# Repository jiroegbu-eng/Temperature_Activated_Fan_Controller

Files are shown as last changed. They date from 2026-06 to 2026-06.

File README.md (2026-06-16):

# Temperature-Activated Fan Controller

A 12V fan controller circuit designed in KiCad. The board turns a cooling fan on or off based on temperature using a 10k NTC thermistor, an LM358 comparator, and an IRLIZ44N MOSFET.

This project is part of my electronics design portfolio. The focus was on building a practical thermal management circuit with a clean schematic, routed PCB layout, and proper ERC/DRC verification.

## Project Summary

The circuit senses temperature through an NTC thermistor voltage divider. A 10k potentiometer sets the fan turn-on threshold. The LM358 compares the thermistor voltage against the threshold voltage, then drives the MOSFET gate when the fan should turn on.

The fan is switched using a low-side MOSFET arrangement. The fan positive terminal is tied to +12V, while the MOSFET controls the ground side of the fan. A 1N4007 diode is placed across the fan output to protect the MOSFET from voltage spikes when the fan turns off.

## Why I Built This

This project is more practical than a simple light sensor circuit because thermal control is common in real electronics systems. Power supplies, motor drivers, amplifiers, embedded boards, and battery systems often need basic fan control or thermal protection.

The project demonstrates:

* Analog sensor interfacing
* Comparator-based switching
* Adjustable threshold control
* Hysteresis feedback
* MOSFET load switching
* Inductive load protection
* PCB layout for power and signal separation

## Main Specifications

| Item | Detail |
| --- | --- |
| Supply voltage | 12V DC |
| Temperature sensor | 10k NTC thermistor @ 25°C |
| Comparator | LM358 |
| Switching device | IRLIZ44N N-channel MOSFET |
| Fan control method | Low-side switching |
| PCB type | 2-layer PCB |
| Design software | KiCad 10.0.1 |
| Simulation | Not included for this project |

## Circuit Operation

The NTC thermistor and a 10k resistor form a voltage divider. As temperature changes, the resistance of the thermistor changes, which also changes the voltage at the `TEMP_SENSE` node.

The 10k potentiometer creates an adjustable reference voltage called `REF_SET`. This lets the fan turn-on point be tuned manually.

The LM358 compares `TEMP_SENSE` against `REF_SET`. When the sensed temperature crosses the set threshold, the LM358 output changes state and drives the MOSFET gate through a 100Ω gate resistor.

The MOSFET switches the fan on the low side. This means the fan receives +12V directly, while the MOSFET connects or disconnects the fan’s ground path.

A 100k resistor provides hysteresis feedback from the comparator output back to the sensing node. This helps stop the fan from rapidly switching on and off when the temperature is close to the threshold.

## Key Design Choices

### NTC Thermistor Divider

The 10k NTC thermistor was paired with a 10k resistor to create a simple temperature-dependent voltage divider. Using equal nominal values around room temperature gives a useful mid-range voltage for the comparator input.

### Adjustable Threshold

A 10k potentiometer was used so the fan turn-on point can be adjusted without changing resistor values. This makes the circuit more flexible and easier to tune.

### Hysteresis Resistor

A 100k feedback resistor was added between the LM358 output and the temperature sensing node. This creates a small amount of hysteresis, which prevents fan chatter around the switching point.

### MOSFET Switching

The IRLIZ44N was selected because it is suitable for low-side switching of 12V fan loads and can be driven from a logic-level control signal. The MOSFET handles the fan current while the LM358 only drives the gate.

### Flyback Protection

The 1N4007 diode is placed across the fan output. Since a fan is an inductive load, it can produce a voltage spike when switched off. The diode gives that energy a safe path and protects the MOSFET.

### PCB Layout

The high-current fan path was routed with wider traces. The low-current sensor and comparator traces were routed separately using smaller traces. The thermistor was placed away from the MOSFET and fan output area to reduce unwanted heating and noise coupling.

## Main Components

| Reference | Component | Value / Part |
| --- | --- | --- |
| U1 | Op-amp / comparator | LM358 |
| Q1 | N-channel MOSFET | IRLIZ44N |
| RT1 | NTC thermistor | 10k @ 25°C |
| RV1 | Potentiometer | 10k |
| R1 | Divider resistor | 10k |
| R2 | Hysteresis resistor | 100k |
| R3 | Gate resistor | 100Ω |
| R4 | Gate pulldown resistor | 100k |
| R5 | LED current-limit resistor | 2.2k |
| D1 | Flyback diode | 1N4007 |
| D2 | Power indicator LED | LED |
| C1 | Decoupling capacitor | 100nF |
| C2 | Bulk capacitor | 10µF |
| J1 | Power input connector | 2-pin screw terminal |
| J2 | Fan output connector | 2-pin screw terminal |

## Verification

The design was checked in KiCad before finalizing the board.

| Check | Result |
| --- | --- |
| ERC | 0 errors |
| DRC | 0 errors |
| Unconnected items | 0 |

## Project Images

### Schematic

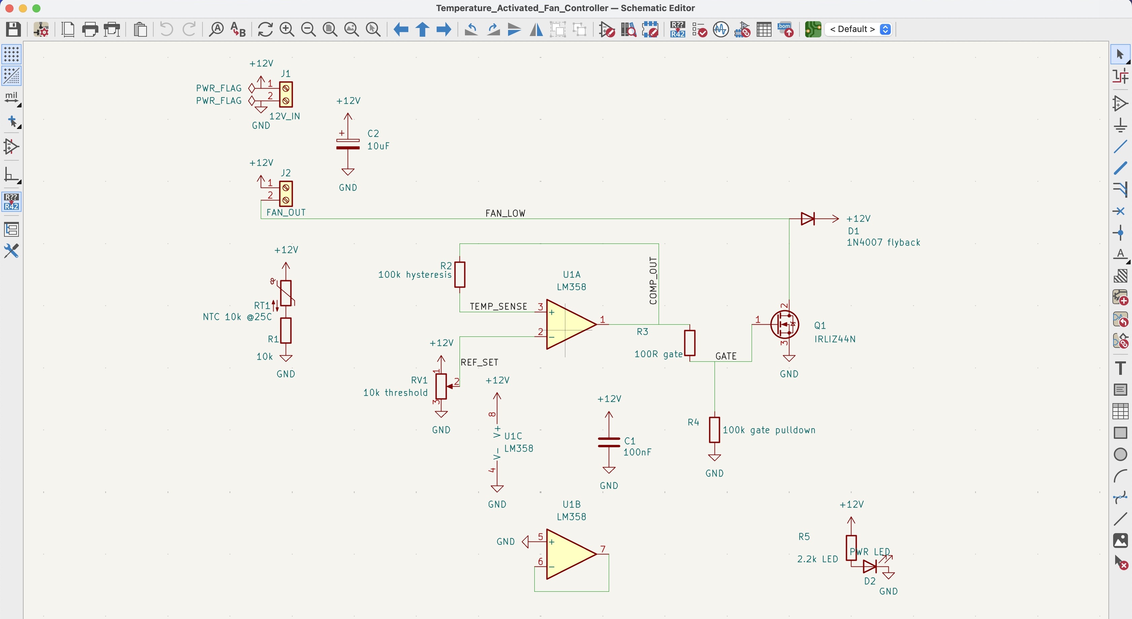
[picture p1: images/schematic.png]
Schematic


### ERC Result

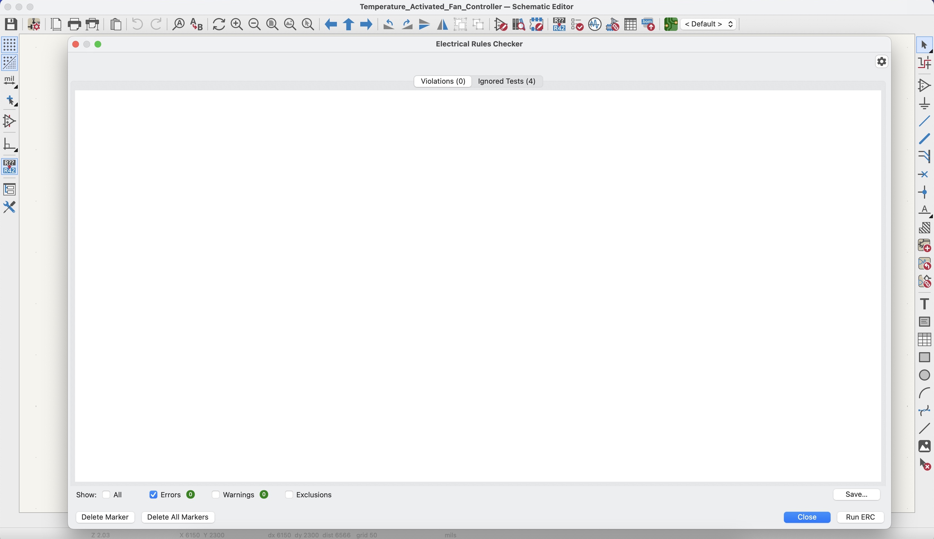
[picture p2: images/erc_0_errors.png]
ERC 0 Errors


### PCB Layout

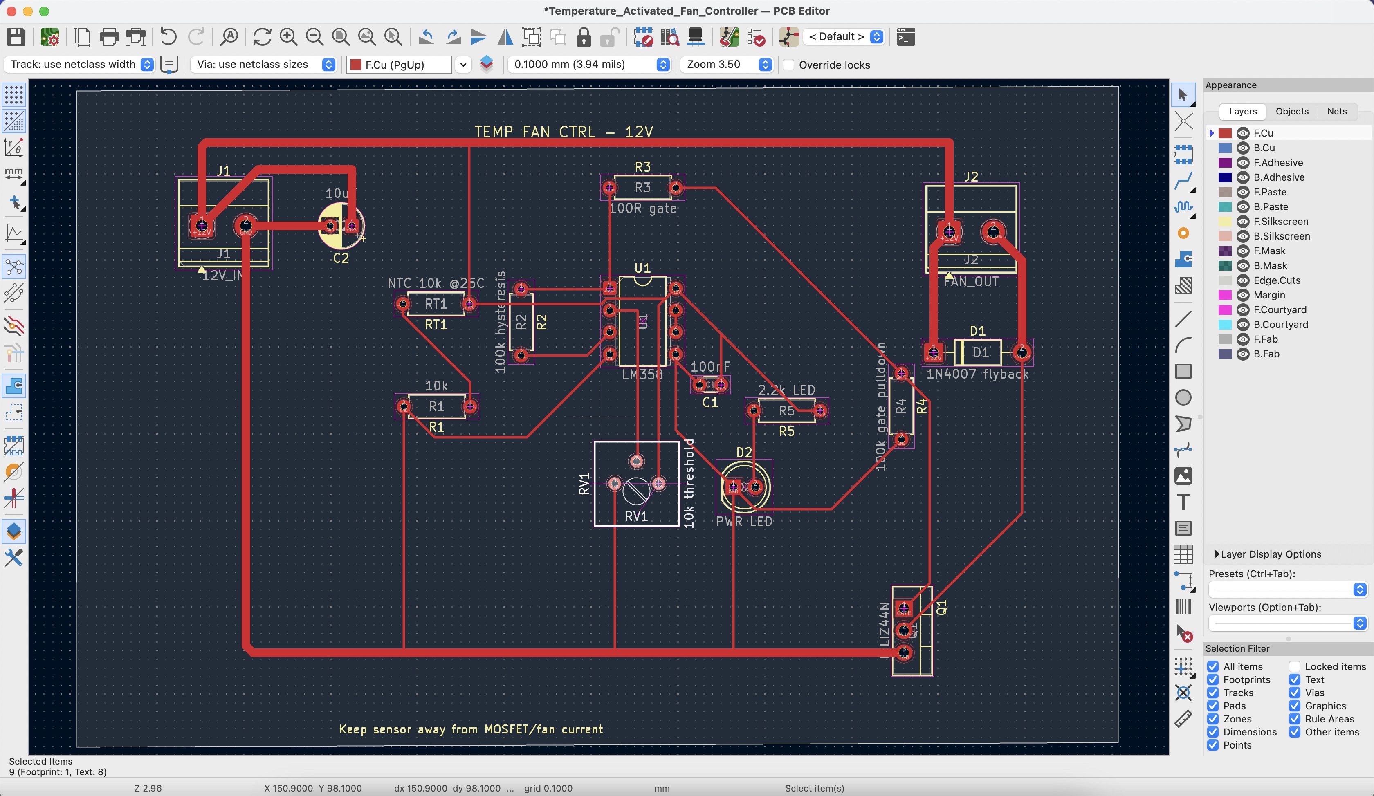
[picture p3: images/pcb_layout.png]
PCB Layout


### DRC Result

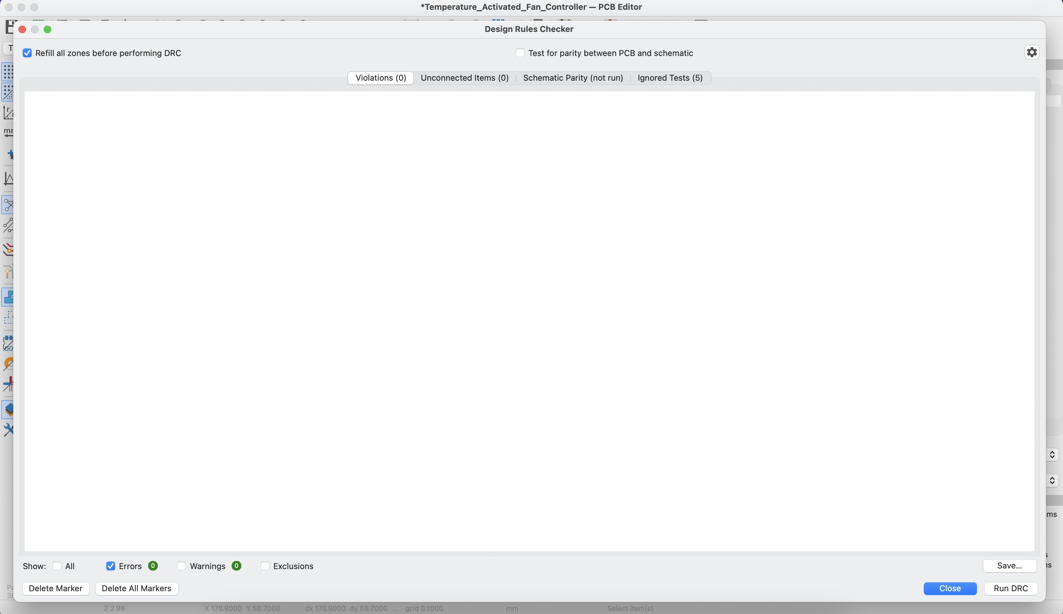
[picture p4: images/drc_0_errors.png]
DRC 0 Errors


### 3D View

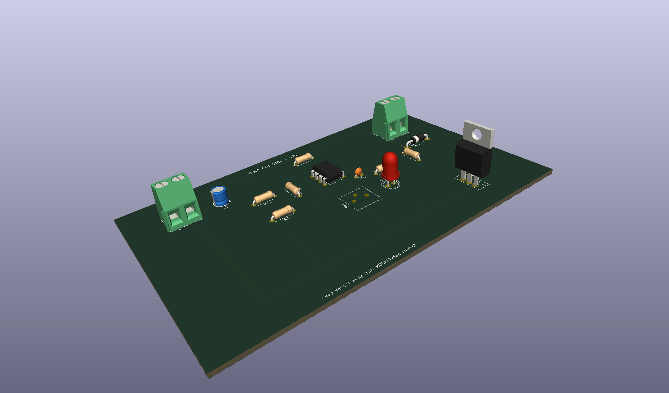
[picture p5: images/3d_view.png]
3D View


## Repository Structure

```text
Temperature_Activated_Fan_Controller/
├── README.md
├── hardware/
│   ├── Temperature_Activated_Fan_Controller.kicad_pro
│   ├── Temperature_Activated_Fan_Controller.kicad_sch
│   ├── Temperature_Activated_Fan_Controller.kicad_pcb
│   └── Temperature_Activated_Fan_Controller.kicad_prl
├── images/
│   ├── schematic.png
│   ├── erc_0_errors.png
│   ├── pcb_layout.png
│   ├── drc_0_errors.png
│   └── 3d_view.png
└── docs/
    └── bom.md
```

## Tools Used

* KiCad 10.0.1
* KiCad Schematic Editor
* KiCad PCB Editor
* KiCad 3D Viewer

## Status

Completed.

* Schematic finished
* PCB layout finished
* ERC passed with 0 errors
* DRC passed with 0 errors
* 3D board preview generated

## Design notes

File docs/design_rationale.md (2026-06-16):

# Design Rationale

## 1. NTC Thermistor Voltage Divider

The temperature sensor section uses a 10k NTC thermistor and a 10k resistor as a voltage divider. The NTC thermistor is connected to +12V, while the fixed 10k resistor is connected to ground. The midpoint between them is the `TEMP_SENSE` signal.

As temperature increases, the resistance of the NTC thermistor decreases. Because of this, the voltage at `TEMP_SENSE` rises. This changing voltage gives the LM358 a simple way to detect temperature changes.

## 2. LM358 Comparator Switching

The LM358 compares two voltages: the temperature voltage from `TEMP_SENSE` and the reference voltage from `REF_SET`.

`TEMP_SENSE` goes into the non-inverting input of the LM358, while `REF_SET` goes into the inverting input. When the temperature rises high enough and `TEMP_SENSE` becomes greater than `REF_SET`, the LM358 output switches high. That output signal then drives the MOSFET gate and turns the fan on.

## 3. Potentiometer Threshold Adjustment

The 10k potentiometer is used to set the fan turn-on threshold. Instead of using fixed resistor values for one fixed temperature point, the potentiometer lets the user adjust when the fan should start running.

This makes the circuit more flexible. The same board can be tuned for different cooling needs by turning the potentiometer.

## 4. 100k Hysteresis Resistor

The 100k resistor feeds a small amount of the LM358 output back into the `TEMP_SENSE` input. This adds hysteresis to the comparator.

Without hysteresis, the fan could rapidly turn on and off when the temperature is very close to the threshold. That kind of switching is called chattering. The 100k feedback resistor helps create a small gap between the turn-on and turn-off points, making the fan behavior more stable.

## 5. IRLIZ44N MOSFET Selection

The IRLIZ44N was selected because it is an N-channel MOSFET suitable for switching 12V fan loads. It is used as a low-side switch, meaning the fan is connected to +12V and the MOSFET controls the ground path.

This is a practical choice because the LM358 only needs to drive the MOSFET gate, while the MOSFET handles the actual fan current. The TO-220 package also gives useful current and heat-handling margin for a small fan controller.

## 6. Flyback Diode Protection

The fan is an inductive load because it contains a motor. When the MOSFET switches the fan off, the motor can produce a voltage spike as the magnetic field collapses.

The 1N4007 flyback diode gives that spike a safe path to circulate instead of forcing it through the MOSFET. The diode cathode is connected to +12V, and the anode is connected to the MOSFET drain side of the fan output. This helps protect the MOSFET from damage.

## 7. PCB Trace Width Choices

The fan current path uses wider traces because it carries more current than the signal section. The main +12V route, fan output route, and MOSFET ground return were routed with wider tracks to reduce resistance, voltage drop, and heating.

The LM358 input signals, potentiometer signals, gate control signal, and LED indicator traces carry very small currents, so smaller traces are enough for those connections. This keeps the board easier to route while still giving the power path enough copper.

## 8. Thermistor Placement Away from MOSFET and Fan Area

The thermistor was placed away from the MOSFET and fan switching area so it can measure ambient temperature more accurately.

The MOSFET and high-current fan traces can generate heat and electrical noise. If the thermistor is too close to that area, it may sense heat from the board instead of the surrounding air. Keeping the thermistor on the quieter side of the board helps the temperature reading stay more realistic.

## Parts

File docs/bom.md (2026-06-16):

# Bill of Materials

| Reference | Component | Value / Part | Package / Footprint Used | Purpose / Notes |
| --- | --- | --- | --- | --- |
| U1 | Dual op-amp / comparator | LM358 | DIP-8 | Used as the comparator. One op-amp section compares the thermistor voltage with the adjustable threshold voltage. The unused second op-amp section is tied off properly so it does not float. |
| Q1 | N-channel MOSFET | IRLIZ44N | TO-220-3 vertical | Low-side switch for the 12V fan. The MOSFET handles the fan current while the LM358 only drives the gate. |
| RT1 | NTC thermistor | 10k @ 25°C | Through-hole thermistor / resistor-style footprint | Temperature sensor. Its resistance decreases as temperature rises, changing the `TEMP_SENSE` voltage. |
| RV1 | Potentiometer | 10k | Bourns 3386P vertical trimmer footprint | Sets the adjustable temperature threshold. Turning the potentiometer changes the `REF_SET` voltage going into the LM358. |
| R1 | Resistor | 10k | Axial through-hole resistor | Forms the lower half of the thermistor voltage divider with RT1. |
| R2 | Resistor | 100k | Axial through-hole resistor | Hysteresis feedback resistor from the LM358 output back to the temperature sense input. Helps prevent fan chatter near the switching point. |
| R3 | Resistor | 100Ω | Axial through-hole resistor | MOSFET gate resistor. Limits sudden gate charging current and helps keep the gate drive stable. |
| R4 | Resistor | 100k | Axial through-hole resistor | MOSFET gate pulldown resistor. Keeps the MOSFET off when the comparator output is inactive or during startup. |
| R5 | Resistor | 2.2k | Axial through-hole resistor | Current-limiting resistor for the power indicator LED. |
| D1 | Rectifier diode | 1N4007 | DO-41 through-hole diode | Flyback diode across the fan output. Protects the MOSFET from voltage spikes when the fan motor switches off. |
| D2 | LED | Power indicator LED  | 5mm through-hole LED | Turns on when the board receives power. Used as a simple power status indicator. |
| C1 | Ceramic capacitor | 100nF | Through-hole disc capacitor | LM358 decoupling capacitor. Helps reduce small supply noise close to the op-amp power pins. |
| C2 | Electrolytic capacitor | 10µF | Radial through-hole capacitor | Bulk input capacitor across the 12V supply. Helps stabilize the input rail when the fan switches. |
| J1 | Screw terminal connector | 2-pin terminal block | 5.08mm pitch through-hole terminal block | 12V DC power input connector. Pin 1 is +12V and pin 2 is GND. |
| J2 | Screw terminal connector | 2-pin terminal block | 5.08mm pitch through-hole terminal block | Fan output connector. Pin 1 connects to +12V and pin 2 connects to `FAN_LOW`, which is switched by the MOSFET. |

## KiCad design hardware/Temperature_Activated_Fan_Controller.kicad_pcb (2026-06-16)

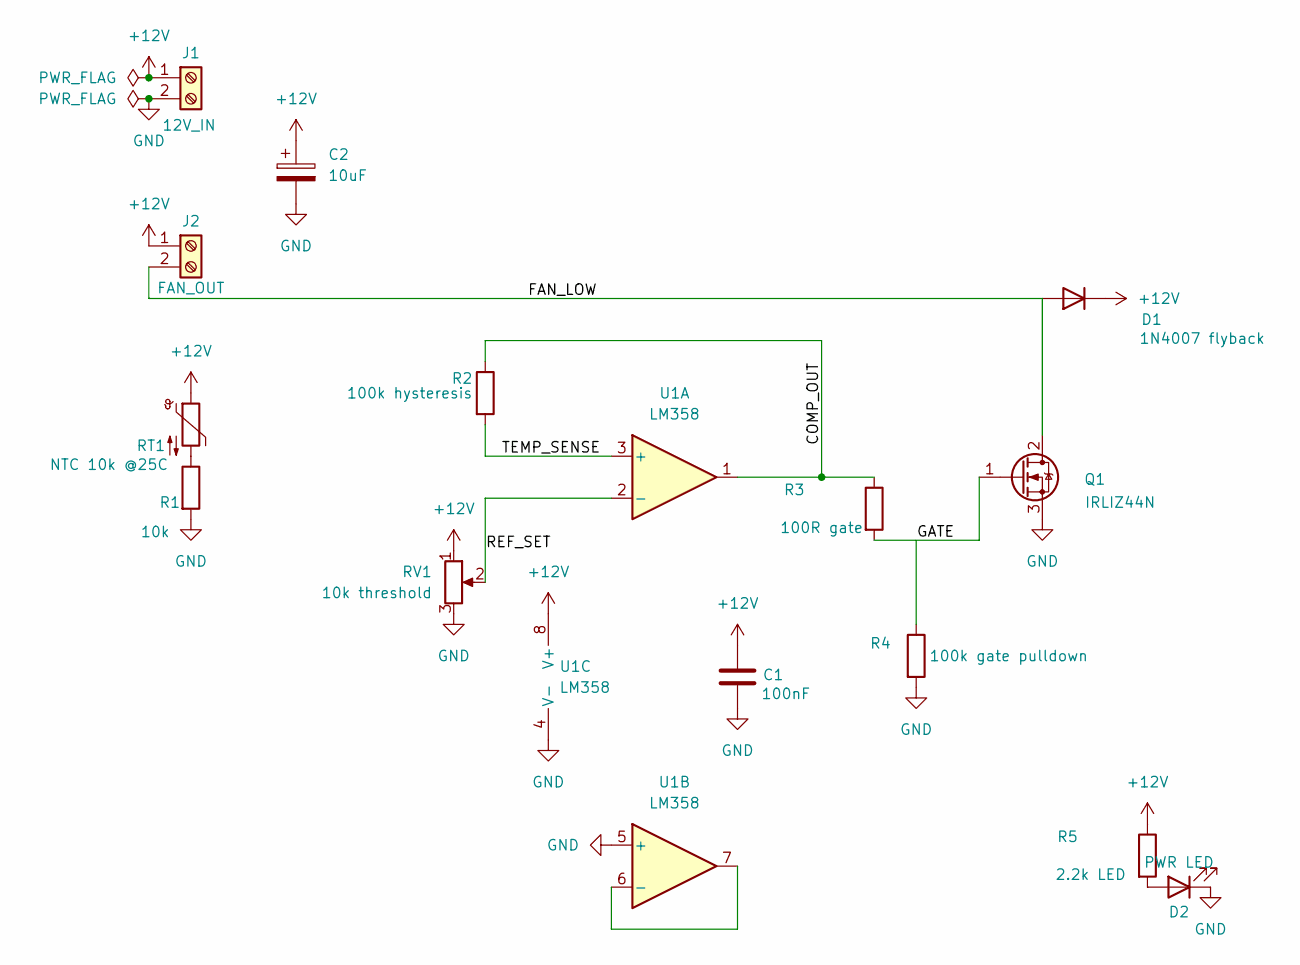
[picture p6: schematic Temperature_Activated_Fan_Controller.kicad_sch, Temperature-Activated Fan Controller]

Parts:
C1: 100nF; C_Disc_D3.0mm_W1.6mm_P2.50mm
C2: 10uF; CP_Radial_D5.0mm_P2.50mm
D1: 1N4007 flyback; D_DO-41_SOD81_P10.16mm_Horizontal
D2: PWR LED; LED_D5.0mm
J1: 12V_IN; TerminalBlock_Phoenix_MKDS-1,5-2-5.08_1x02_P5.08mm_Horizont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
J2: FAN_OUT; TerminalBlock_Phoenix_MKDS-1,5-2-5.08_1x02_P5.08mm_Horizont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
Q1: IRLIZ44N; TO-220-3_Vertical
R1: 10k; R_Axial_DIN0207_L6.3mm_D2.5mm_P7.62mm_Horizontal
R2: 100k hysteresis; R_Axial_DIN0207_L6.3mm_D2.5mm_P7.62mm_Horizontal
R3: 100R gate; R_Axial_DIN0207_L6.3mm_D2.5mm_P7.62mm_Horizontal
R4: 100k gate pulldown; R_Axial_DIN0207_L6.3mm_D2.5mm_P7.62mm_Horizontal
R5: 2.2k LED; R_Axial_DIN0207_L6.3mm_D2.5mm_P7.62mm_Horizontal
RT1: NTC 10k @25C; R_Axial_DIN0207_L6.3mm_D2.5mm_P7.62mm_Horizontal
RV1: 10k threshold; Potentiometer_Bourns_3386P_Vertical
U1: LM358; DIP-8_W7.62mm

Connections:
+12V: C1.1, C2.1, D1.1 (K), J1.1, J2.1, R5.1, RT1.1, RV1.1, U1.8 (V+)
/COMP_OUT: R2.1, R3.1, U1.1
/FAN_LOW: D1.2 (A), J2.2, Q1.2 (D)
/GATE: Q1.1 (G), R3.2, R4.1
/REF_SET: RV1.2, U1.2 (-)
/TEMP_SENSE: R2.2, U1.3 (+)
GND: C1.2, C2.2, D2.1 (K), J1.2, Q1.3 (S), R1.2, R4.2, RV1.3, U1.4 (V-), U1.5 (+)
unnamed: D2.2 (A), R5.2
unnamed: R1.1, RT1.2
unnamed: U1.6 (-), U1.7

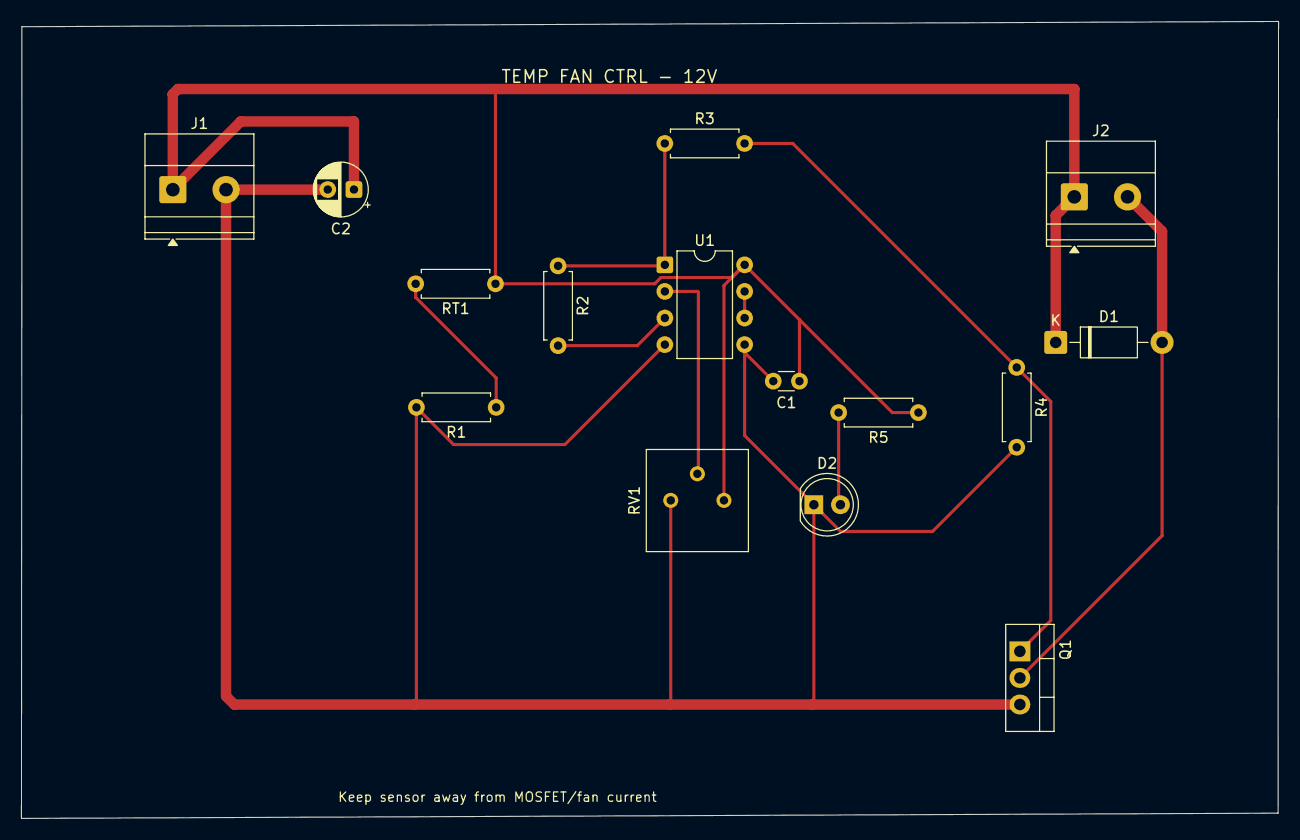
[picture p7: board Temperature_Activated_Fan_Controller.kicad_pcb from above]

Board: 2 copper layers, 120.0 x 76.1 mm, 15 parts (0 on the bottom side), 10 nets.

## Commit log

2026-06-16 Add KiCad schematic, PCB layout for fan controller
    [Temperature_Activated_Fan_Controller.kicad_pcb, Temperature_Activated_Fan_Controller.kicad_sch]
2026-06-16 Add detailed BOM document
2026-06-16 Complete temperature-activated fan controller project
